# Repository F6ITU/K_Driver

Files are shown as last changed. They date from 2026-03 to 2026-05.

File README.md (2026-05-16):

# K_Driver
Ajax Telamon, 10 to 30 dBm driver to feed LDMOS RF amplifier

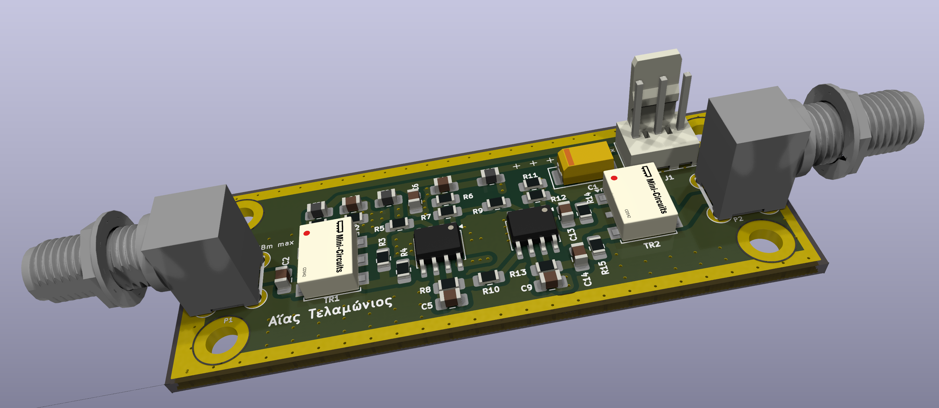
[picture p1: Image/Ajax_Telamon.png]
Le driver


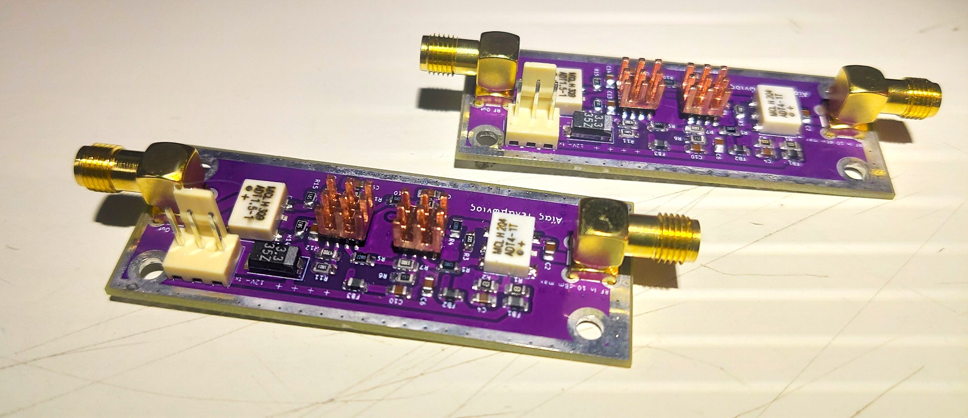
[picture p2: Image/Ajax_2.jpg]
La realisation


Ajax is a cascade of four OPA2674 op-amps, designed to amplify the signal from a DAC by around 20/25 dB (between 0 to 5 dBm of input power 27 dBm out). 

The comfort zone of this amplifier is around half a watt of power.

The origin of the diagram is lost in the mists of time.

It can be found in the archives of the OpenHPSDR Penelope and Pennylane project, a 1/2 watt exciter (https://openhpsdr.org/wiki/index.php?title=PENELOPE) 
(following a AD9744ARU DAC).

It is also used in the 14HAM-DK2, an impressive project by F4JGL.  (https://sites.google.com/view/projet-14ham-dk2/les-%C3%A9l%C3%A9ments-du-projet/modules-ampli-hf-%C3%A9mission/module-driver). 

It is used to directly attack a push-pull made of MRF101AN/BN , in other words Kjell LA2NI's OpenHPSDR "MUNIN 100" amplifier (https://github.com/F6ITU/K_Munin100_Fork)

This umpteenth version has no other ambition than to provide exactly the same "service," but in a smaller size, with the PCB measuring only 6.5 x 2.5 cm.

The shielding of the assembly is left to the discretion of each user.

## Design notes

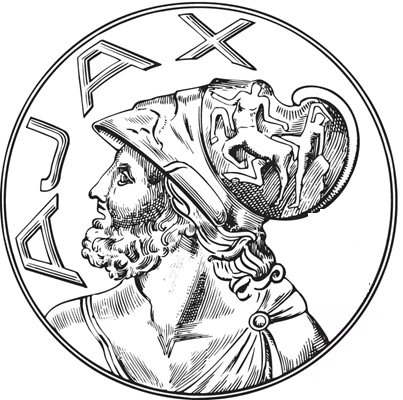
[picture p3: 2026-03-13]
Image/Ajax.png

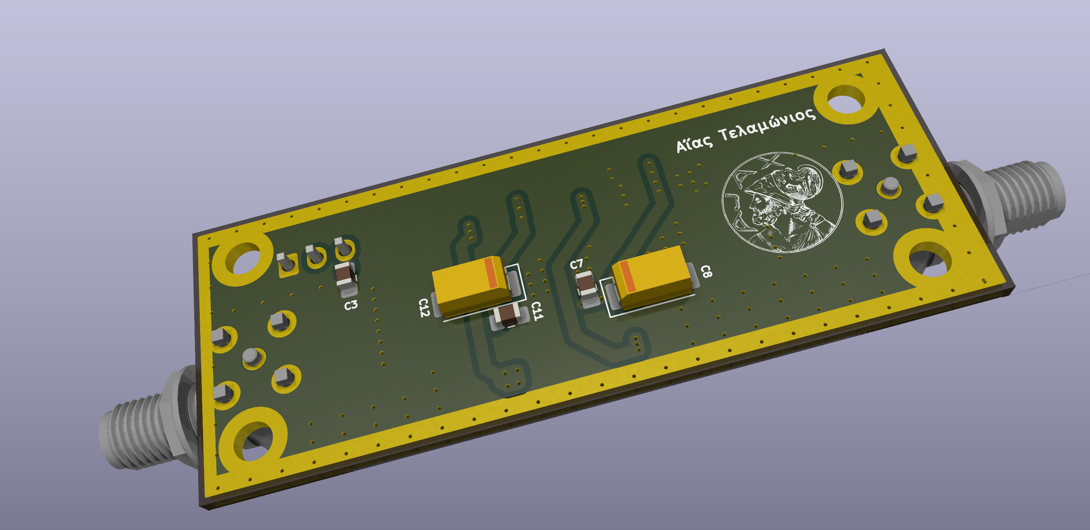
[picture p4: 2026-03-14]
Image/Ajax_Telamon_down.png

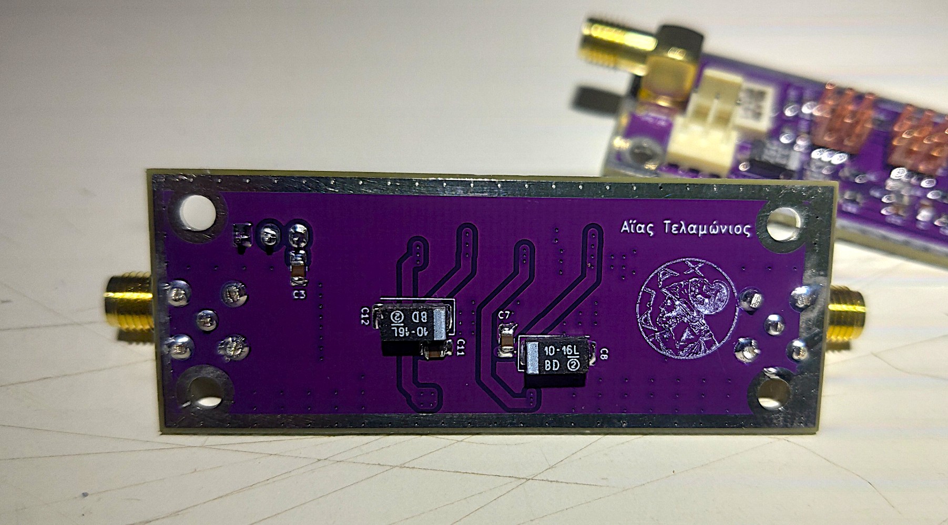
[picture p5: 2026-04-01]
Image/ajax_1.jpg

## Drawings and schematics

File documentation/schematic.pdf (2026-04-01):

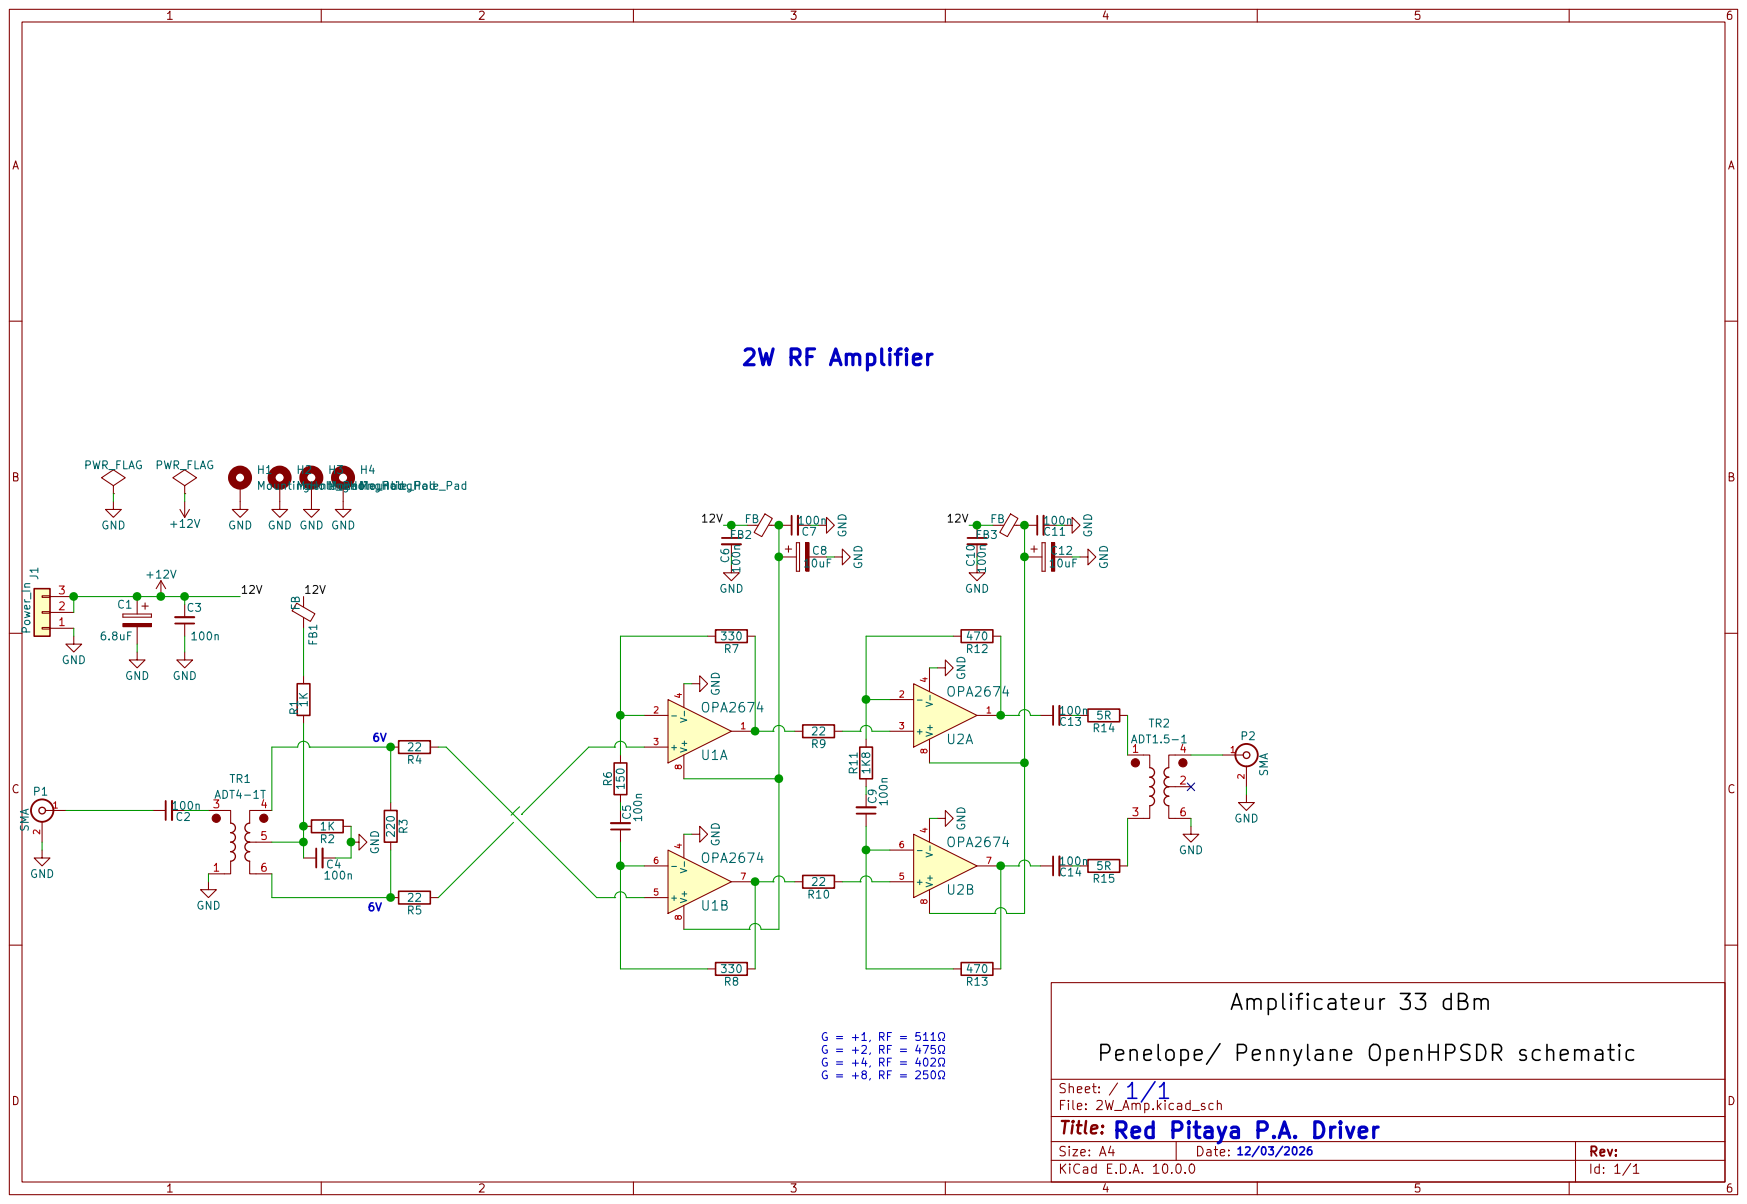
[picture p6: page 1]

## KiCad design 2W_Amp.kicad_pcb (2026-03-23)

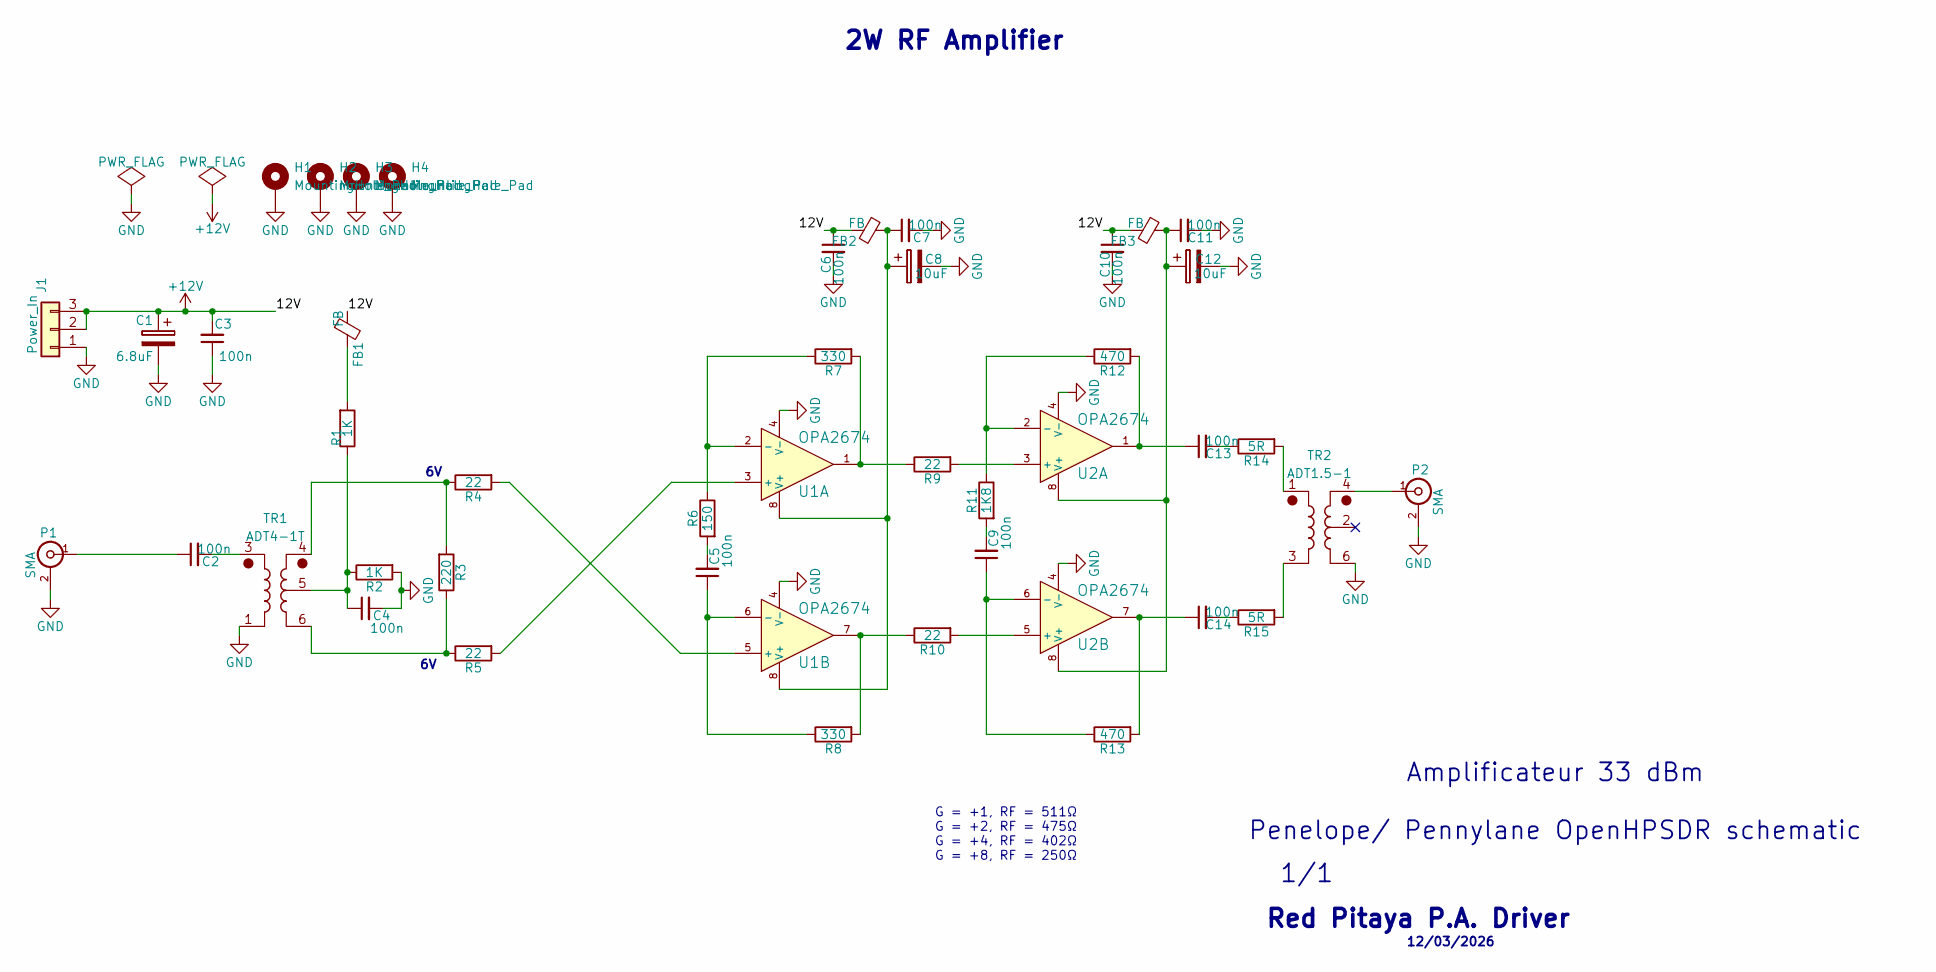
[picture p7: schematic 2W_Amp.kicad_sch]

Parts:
C1: 6.8uF; CP_EIA-6032-28_Kemet-C_HandSolder
C2, C3, C4, C5, C6, C7, C9, C10, C11, C13, C14: 100n; C_0805_2012Metric_Pad1.18x1.45mm_HandSolder
C8, C12: 10uF; CP_EIA-6032-28_Kemet-C_HandSolder
FB1, FB2, FB3: FB; R_0805_2012Metric_Pad1.20x1.40mm_HandSolder
H1, H2, H3, H4: MountingHole_Pad; MountingHole_3.2mm_M3_DIN965_Pad_TopBottom
J1: Power_In; Molex_KK-254_AE-6410-03A_1x03_P2.54mm_Vertical
P1, P2: SMA; SMA_PINS
R1, R2: 1K; R_0805_2012Metric_Pad1.20x1.40mm_HandSolder
R3: 220; R_0805_2012Metric_Pad1.20x1.40mm_HandSolder
R4, R5, R9, R10: 22; R_0805_2012Metric_Pad1.20x1.40mm_HandSolder
R6: 150; R_0805_2012Metric_Pad1.20x1.40mm_HandSolder
R7, R8: 330; R_0805_2012Metric_Pad1.20x1.40mm_HandSolder
R11: 1K8; R_0805_2012Metric_Pad1.20x1.40mm_HandSolder
R12, R13: 470; R_0805_2012Metric_Pad1.20x1.40mm_HandSolder
R14, R15: 5R; R_0805_2012Metric_Pad1.20x1.40mm_HandSolder
TR1: ADT4-1T; Mini-Circuits_CD542_H2.84mm
TR2: ADT1.5-1; Mini-Circuits_CD542_H2.84mm
U1, U2: OPA2674; SOIC-8_3.9x4.9mm_P1.27mm

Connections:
+12V: C1.1, C3.2, C6.1, C10.1, FB1.1, FB2.2, FB3.2, J1.2, J1.3
GND: C1.2, C3.1, C4.2, C6.2, C7.2, C8.2, C10.2, C11.2, C12.2, H1.1, H2.1, H3.1, H4.1, J1.1, P1.2 (Ext), P2.2 (Ext), R2.2, TR1.1, TR2.6, U1.4 (V-), U2.4 (V-)
unnamed: C2.2, TR1.3
unnamed: C4.1, R1.1, R2.1, TR1.5
unnamed: C5.2, R6.2
unnamed: C9.2, R11.2
unnamed: C13.1, R12.2, U2.1
unnamed: C13.2, R14.1
unnamed: C14.1, R13.2, U2.7
unnamed: C14.2, R15.1
unnamed: FB1.2, R1.2
unnamed: C2.1, P1.1 (In)
unnamed: P2.1 (In), TR2.4
unnamed: R3.1, R5.1, TR1.6
unnamed: R3.2, R4.1, TR1.4
unnamed: R7.2, R9.1, U1.1
unnamed: R8.2, R10.1, U1.7
unnamed: R14.2, TR2.1
unnamed: R15.2, TR2.3
unnamed: R5.2, U1.3 (+)
unnamed: R6.1, R7.1, U1.2 (-)
unnamed: C7.1, C8.1, FB2.1, U1.8 (V+)
unnamed: R4.2, U1.5 (+)
unnamed: C5.1, R8.1, U1.6 (-)
unnamed: R9.2, U2.3 (+)
unnamed: R11.1, R12.1, U2.2 (-)
unnamed: C11.1, C12.1, FB3.1, U2.8 (V+)
unnamed: R10.2, U2.5 (+)
unnamed: C9.1, R13.1, U2.6 (-)

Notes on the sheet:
1/1
Amplificateur 33 dBm Penelope/ Pennylane OpenHPSDR schematic
2W RF Amplifier
G = +1, RF = 511Ω G = +2, RF = 475Ω G = +4, RF = 402Ω G = +8, RF = 250Ω
12/03/2026
Red Pitaya P.A. Driver

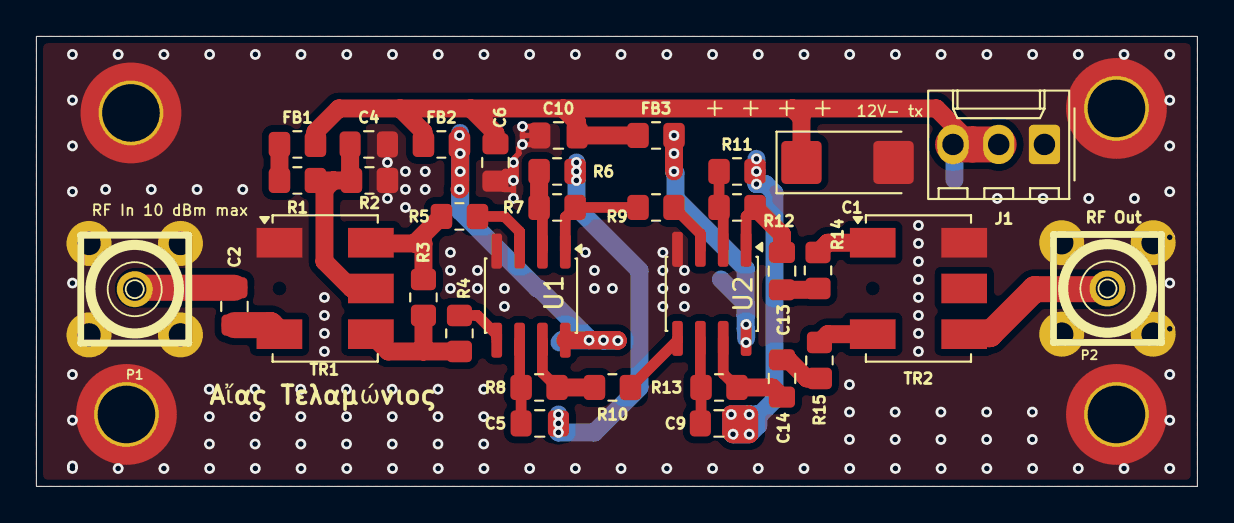
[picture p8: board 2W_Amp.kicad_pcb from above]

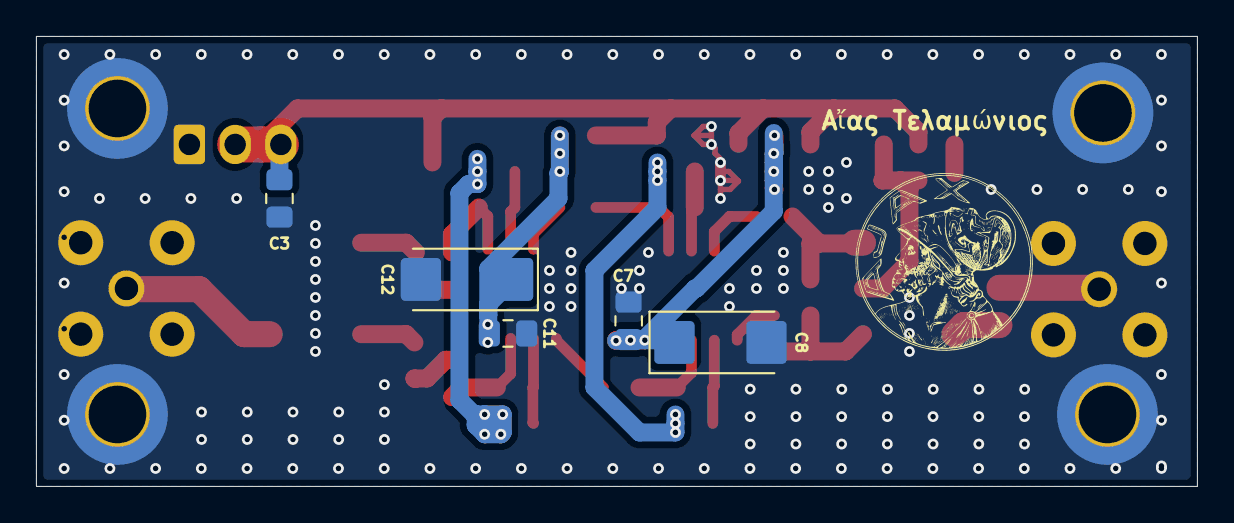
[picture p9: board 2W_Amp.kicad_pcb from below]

Board: 2 copper layers, 64.5 x 25.0 mm, 43 parts (5 on the bottom side), 29 nets.

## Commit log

2026-03-13 first commit with gerber and iBom
    [2W_Amp-B_Cu.gbl, 2W_Amp-B_Mask.gbs, 2W_Amp-B_Paste.gbp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]
2026-03-13 some cleanup later...
    [2W_Amp-B_Cu.gbl, 2W_Amp-B_Mask.gbs, 2W_Amp-B_Paste.gbp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]
2026-03-13 yet some other small adjustments
    [2W_Amp.kicad_pcb]
2026-03-13 yet some other other small adjustments
    [2W_Amp-B_Cu.gbl, 2W_Amp-B_Mask.gbs, 2W_Amp-B_Paste.gbp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]
2026-03-14 decoupling on lower side, documentation added
    [2W_Amp-B_Cu.gbl, 2W_Amp-B_Mask.gbs, 2W_Amp-B_Paste.gbp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]
2026-03-23 kicad 10 update
    [2W_Amp.kicad_pcb, 2W_Amp.kicad_sch]
2026-04-01 picture and schematic pdf file added
2026-05-16 minor cosmetic changes
    [2W_Amp.kicad_sch]
